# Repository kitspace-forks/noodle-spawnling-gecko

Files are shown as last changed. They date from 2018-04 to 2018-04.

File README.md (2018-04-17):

# Noodle Spawnling Gecko Brain

This is a brain for a [noodle spawnling](http://roboticarts.zoness.com/2017/12/19/birthing-a-noodle-spawnling/), a small 3d-printed robot figurine designed by spetku.

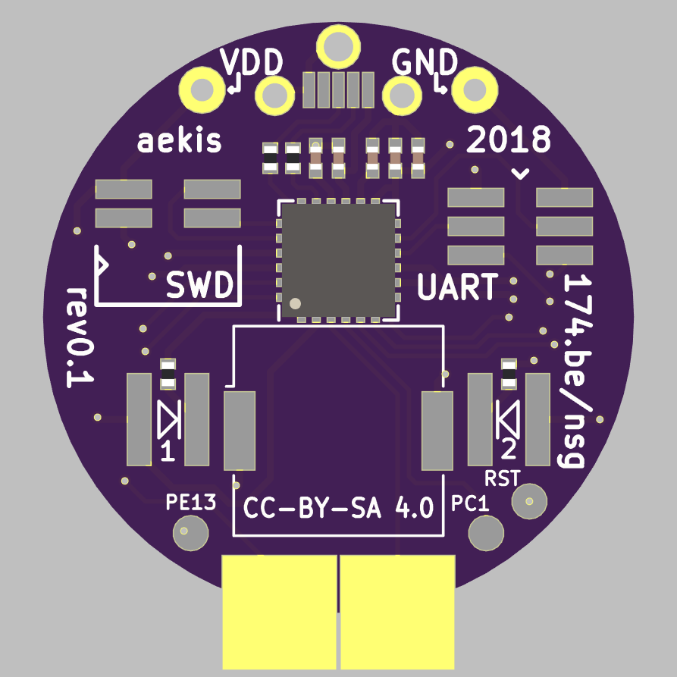
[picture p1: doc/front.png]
Rendered view of the PCB front side


I am building a noodle spawnling for myself and also wanted to learn more about programming ARM Cortex uCs, so I made this brain board to do both at the same time.

## Features
  * Silicon Labs Happy Gecko EFM32HG309 microcontroller (the same one as on the [tomu.im](https://tomu.im))
  * buzzer
  * 2 LEDs
  * capacitive touch button area
  * micro USB connector
  * SWD debug and a combined (LEU/US)ART header
  * CR2032 coincell holder

For the BOM see [doc/bom.csv](doc/bom.csv).

## Additional tools
Besides KiCad, some additional tools were used on this project:
  * For BOM management I used [BOMs Away](https://github.com/Jeff-Ciesielski/Boms-Away)
  * [doc/stickerbom.pdf](doc/stickerbom.pdf) was generated with [StickerBOM](https://github.com/adamgreig/agg-kicad/wiki/StickerBOM)

## License
CC BY-SA 4.0 (https://creativecommons.org/licenses/by-sa/4.0/)

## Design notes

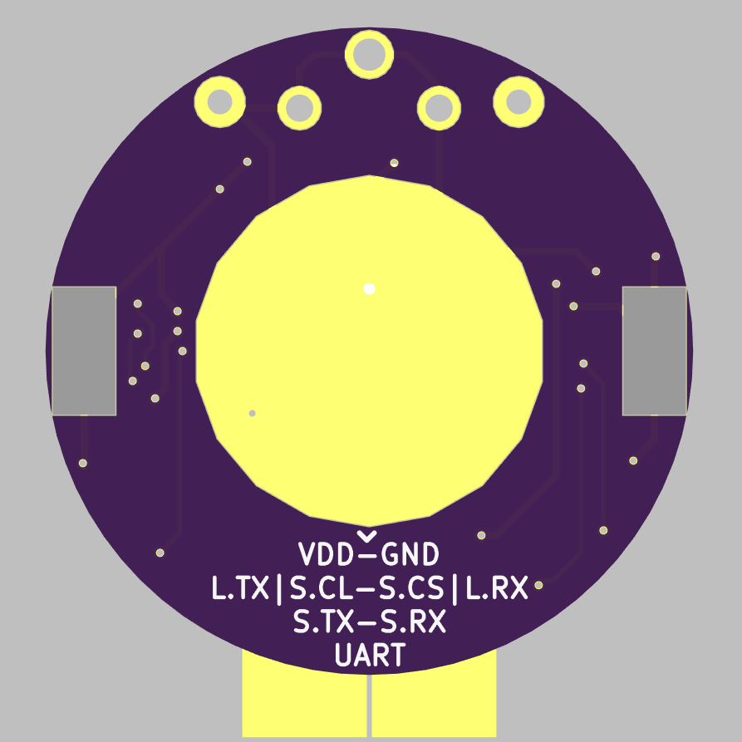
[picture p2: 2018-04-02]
doc/back.png

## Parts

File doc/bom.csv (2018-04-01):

Refs | Value | Footprint | QTY | MFR | MPN | SPR | SPN
BZ1 | Buzzer | Buzzers_Beepers:Buzzer_Murata_PKMCS0909E4000-R1 | 1 | Murata Electronics North America | PKMCS0909E4000-R1 | Digikey | 490-9647-1-ND
C5 | 100nF | Capacitors_SMD:C_0402_NoSilk | 1 | Samsung Electro-Mechanics | CL05A104KQ5NNNC | Digikey | 1276-1442-1-ND
C4 | 10uF | Capacitors_SMD:C_0402_NoSilk | 1 | Murata Electronics North America | GRM155C80J106ME11D | Digikey | 490-13233-1-ND
C3;C2 | 1uF | Capacitors_SMD:C_0402_NoSilk | 2 | Samsung Electro-Mechanics | CL05X105KQ5NNNC | Digikey | 1276-1754-1-ND
C1 | 4.7uF | Capacitors_SMD:C_0402_NoSilk | 1 | Samsung Electro-Mechanics | CL05A475KQ5NRNC | Digikey | 1276-1481-1-ND
U1 | EFM32HG309 | Housings_DFN_QFN:QFN-24-1EP_5x5mm_Pitch0.65mm | 1 | Silicon Labs | EFM32HG309F64G-B-QFN24 | Digikey | 336-3896-ND
R3;R4 | 15 Ohm | Resistors_SMD:R_0402_NoSilk | 2 | Panasonic Electronic Components | ERJ-2RKF15R0X | Digikey | P15.0LCT-ND
R1;R2 | R | Resistors_SMD:R_0402_NoSilk | 2 | Yageo | RC0402FR-0752R3L | Digikey | YAG3180CT-ND
BT1 | Battery_Cell | coincell_smd:CR2032_holder_smd | 1 | Linx Technologies Inc. | BAT-HLD-001 | Digikey | BAT-HLD-001-ND
J5 | EXT_PWR_GND | headers-tht:Pin_d1.0mm_L10.0mm_noSilk | 1 | Amphenol FCI | 68000-401HLF | Digikey | 609-3466-ND
J4 | EXT_PWR_VDD | headers-tht:Pin_d1.0mm_L10.0mm_noSilk | 1 | Amphenol FCI | 68000-401HLF | Digikey | 609-3466-ND
J7 | DEBUG_HEADER | headers_smd:header_smd_0.05pitch_2row_4pin | 1 | Sullins Connector Solutions | GRPB022VWQS-RC | Digikey | S9012E-02-ND
J6 | LEU0/US0_HEADER | headers_smd:header_smd_0.05pitch_2row_6pin | 1 | Amphenol FCI | 20021121-00006C4LF | Digikey | 609-3693-1-ND
SW1 | CAP_TOUCH_BTN | pcb_pads:cap_touch_pads | 1 | - | - | - | -
D1;D2 | LED | pcb_pads:led_5mm_horizontal_pads | 2 | Wurth Electronics Inc. | 151051SS04000 | Digikey | 732-11405-ND
J1 | GPIO_PC1_PAD | pcb_pads:pcb_pad_single_1,5mm | 1 | - | - | - | -
J2 | GPIO_PE13_PAD | pcb_pads:pcb_pad_single_1,5mm | 1 | - | - | - | -
J3 | RESETn_PAD | pcb_pads:pcb_pad_single_1,5mm | 1 | - | - | - | -
J8 | USB_MICRO_B | usb_smd:usb_microb_smd_vertical | 1 | Molex, LLC | 1051330011 | Digikey | WM10134CT-ND

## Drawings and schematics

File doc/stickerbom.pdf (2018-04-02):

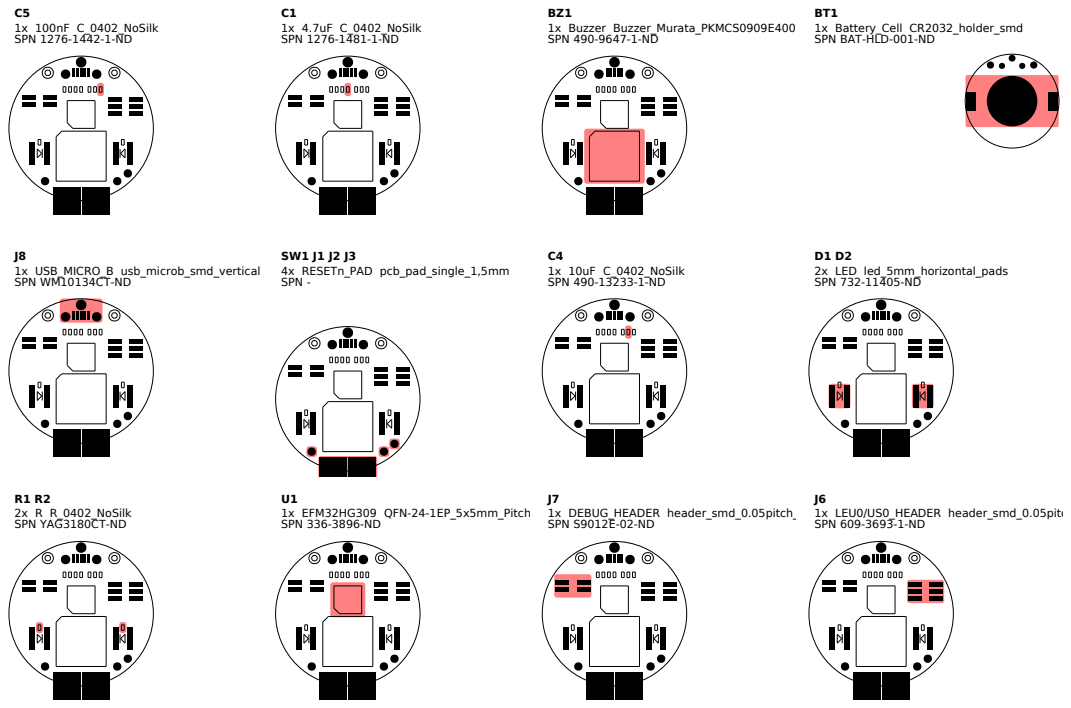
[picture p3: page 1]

J4 J5
2x EXT_PWR_GND Pin_d1.0mm_L10.0mm_noSilk SPN 609-3466-ND

R3 R4
2x 15 Ohm R_0402_NoSilk
SPN P15.0LCT-ND

C3 C2
2x 1uF C_0402_NoSilk
SPN 1276-1754-1-ND

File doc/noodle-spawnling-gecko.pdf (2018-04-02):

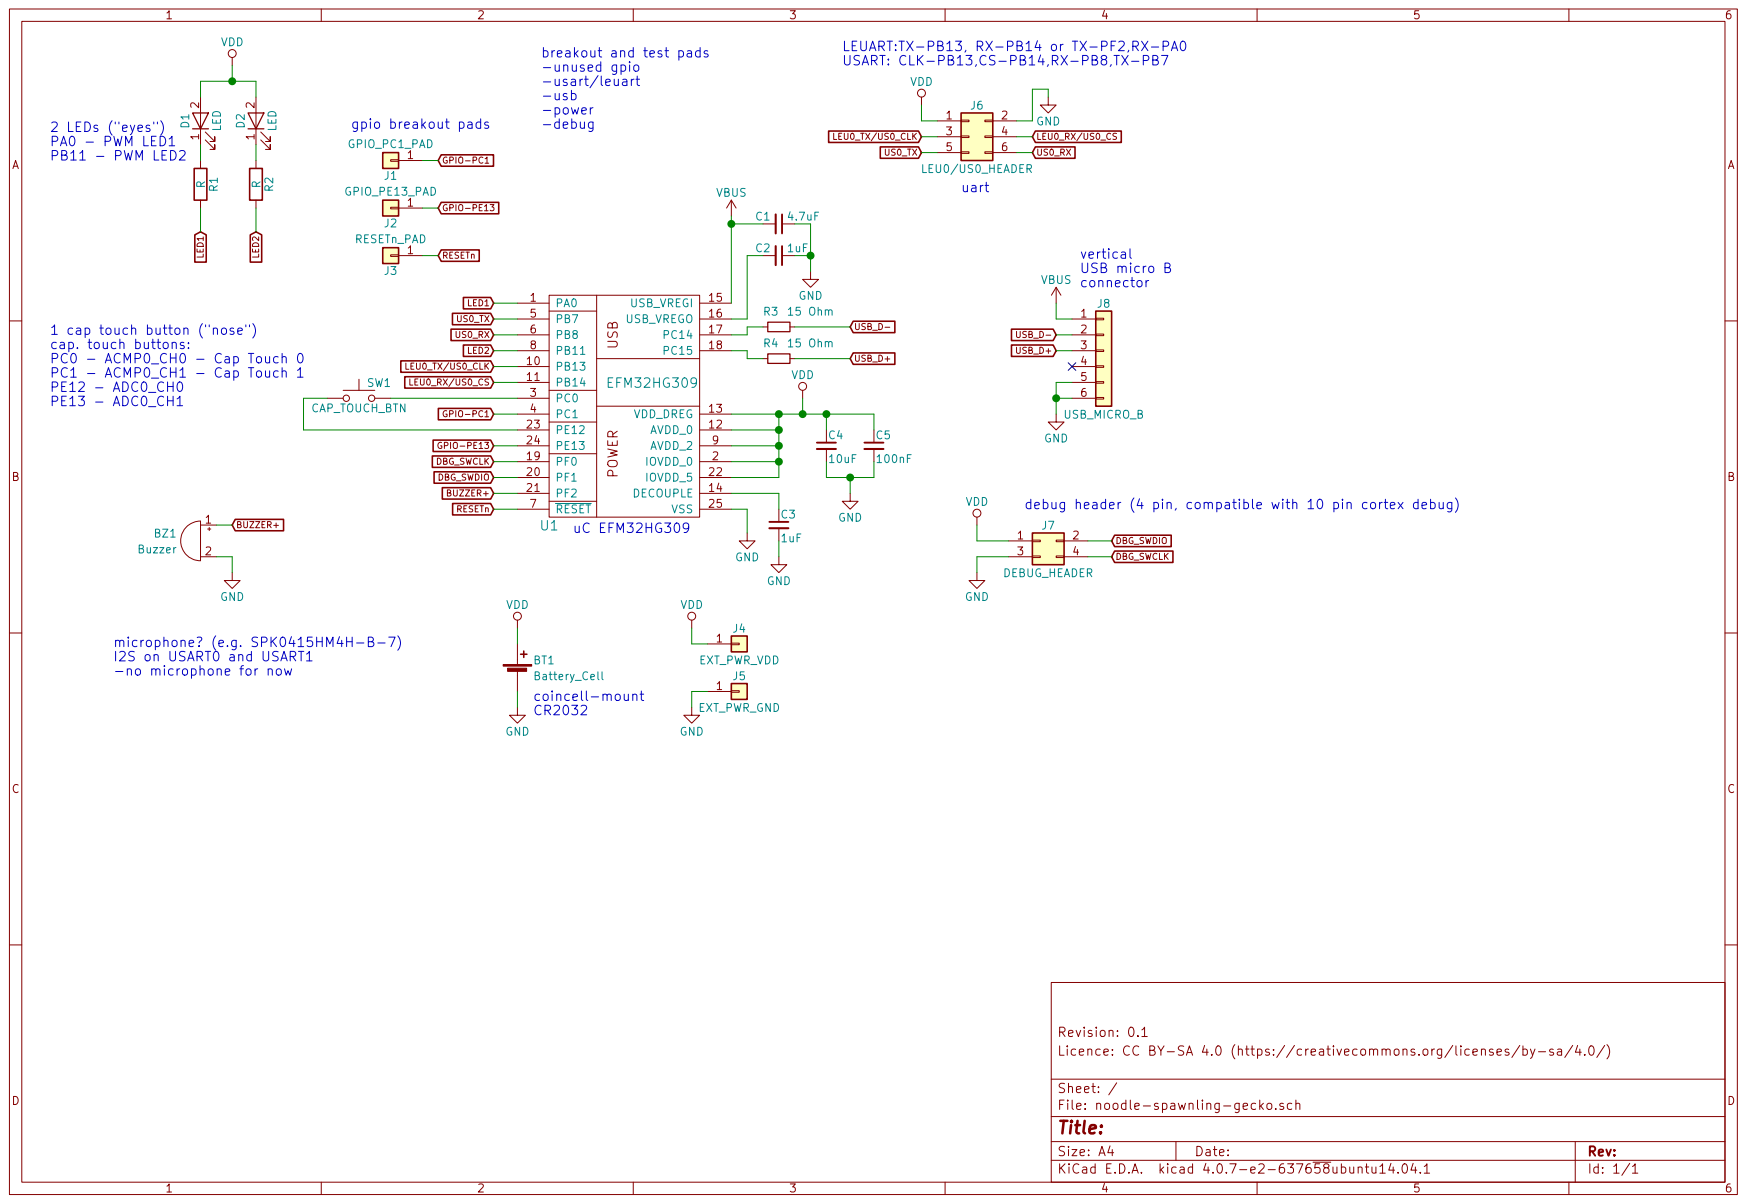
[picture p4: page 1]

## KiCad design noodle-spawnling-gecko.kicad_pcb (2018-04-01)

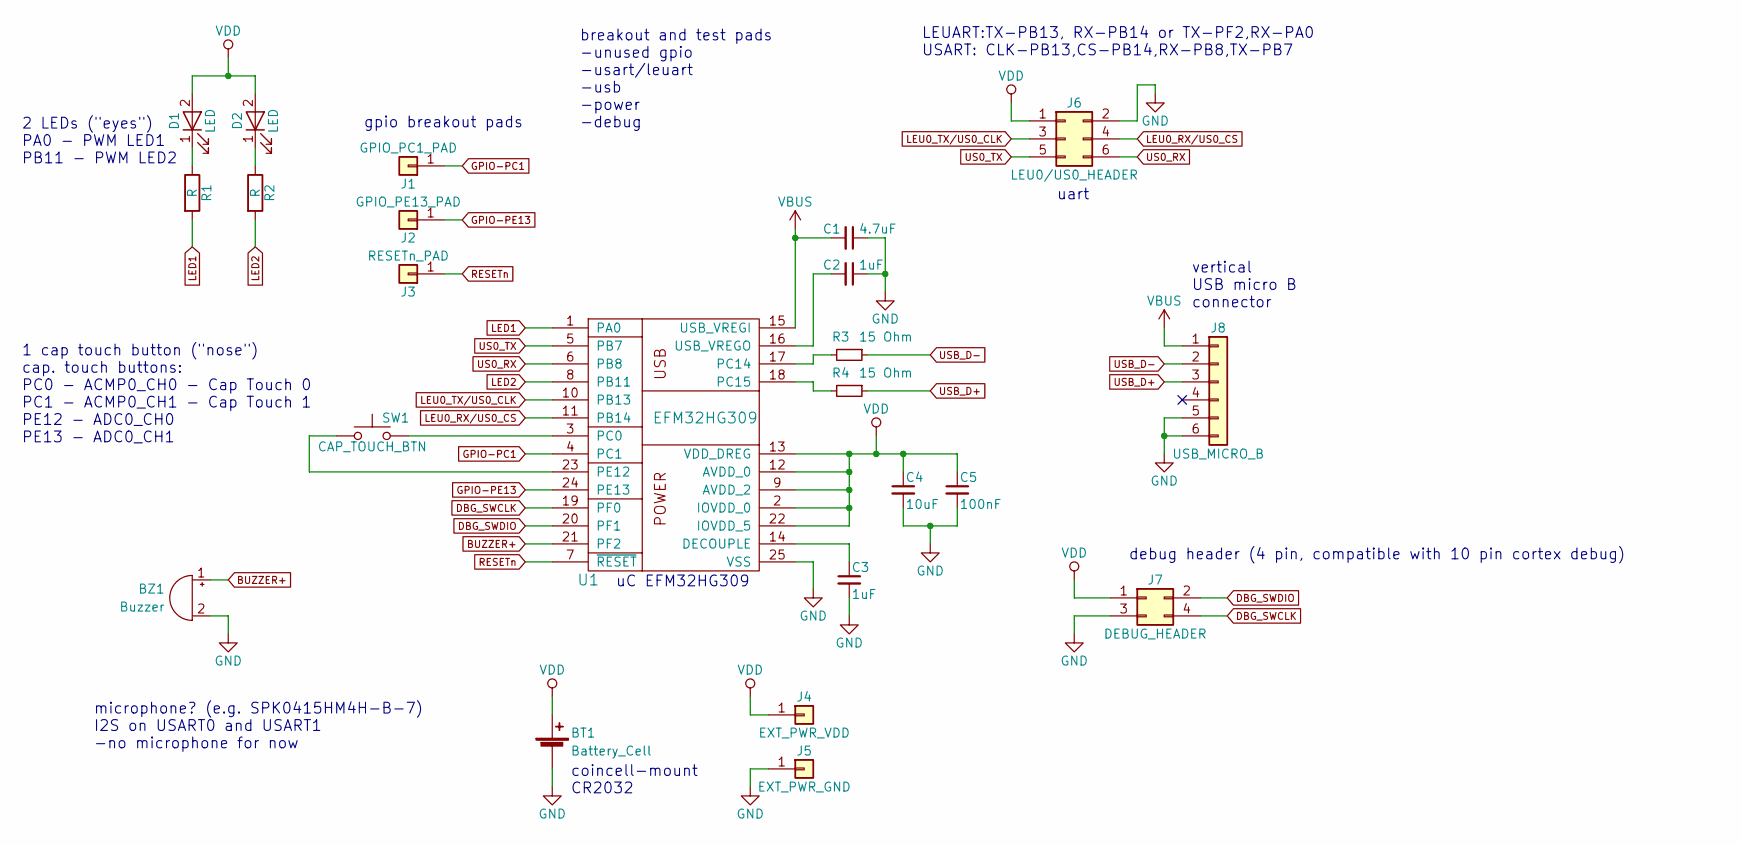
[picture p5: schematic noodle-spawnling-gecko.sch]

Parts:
BT1: Battery_Cell; CR2032_holder_smd
BZ1: Buzzer; Buzzer_Murata_PKMCS0909E4000-R1
C1: 4.7uF; C_0402_NoSilk
C2, C3: 1uF; C_0402_NoSilk
C4: 10uF; C_0402_NoSilk
C5: 100nF; C_0402_NoSilk
D1, D2: LED; led_5mm_horizontal_pads
J1: GPIO_PC1_PAD; pcb_pad_single_1,5mm
J2: GPIO_PE13_PAD; pcb_pad_single_1,5mm
J3: RESETn_PAD; pcb_pad_single_1,5mm
J4: EXT_PWR_VDD; Pin_d1.0mm_L10.0mm_noSilk
J5: EXT_PWR_GND; Pin_d1.0mm_L10.0mm_noSilk
J6: LEU0/US0_HEADER; header_smd_0.05pitch_2row_6pin
J7: DEBUG_HEADER; header_smd_0.05pitch_2row_4pin
J8: USB_MICRO_B; usb_microb_smd_vertical
R1, R2: R; R_0402_NoSilk
R3, R4: 15 Ohm; R_0402_NoSilk
SW1: CAP_TOUCH_BTN; cap_touch_pads
U1: EFM32HG309; QFN-24-1EP_5x5mm_Pitch0.65mm

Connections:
BUZZER+: BZ1.1 (-), U1.21 (PF2)
DBG_SWCLK: J7.4, U1.19 (PF0)
DBG_SWDIO: J7.2, U1.20 (PF1)
GND: BT1.2 (-), BZ1.2 (+), C1.1, C2.1, C3.2, C4.2, C5.2, J5.1, J6.2, J7.3, J8.5, J8.6, U1.25 (VSS)
GPIO-PC1: J1.1, U1.4 (PC1)
GPIO-PE13: J2.1, U1.24 (PE13)
LED1: R1.2, U1.1 (PA0)
LED2: R2.2, U1.8 (PB11)
LEU0_RX/US0_CS: J6.4, U1.11 (PB14)
LEU0_TX/US0_CLK: J6.3, U1.10 (PB13)
unnamed: C2.2, U1.16 (USB_VREGO)
unnamed: C3.1, U1.14 (DECOUPLE)
unnamed: D1.1 (K), R1.1
unnamed: D2.1 (K), R2.1
unnamed: R3.2, U1.17 (PC14)
unnamed: R4.2, U1.18 (PC15)
unnamed: SW1.1, U1.23 (PE12)
unnamed: SW1.2, U1.3 (PC0)
RESETn: J3.1, U1.7 (~RESET)
US0_RX: J6.6, U1.6 (PB8)
US0_TX: J6.5, U1.5 (PB7)
USB_D+: J8.3, R4.1
USB_D-: J8.2, R3.1
VBUS: C1.2, J8.1, U1.15 (USB_VREGI)
VDD: BT1.1 (+), C4.1, C5.1, D1.2 (A), D2.2 (A), J4.1, J6.1, J7.1, U1.2 (IOVDD_0), U1.9 (AVDD_2), U1.12 (AVDD_0), U1.13 (VDD_DREG), U1.22 (IOVDD_5)

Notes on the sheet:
uC EFM32HG309
2 LEDs ("eyes") PA0 - PWM LED1 PB11 - PWM LED2
debug header (4 pin, compatible with 10 pin cortex debug)
coincell-mount CR2032
vertical USB micro B connector
breakout and test pads -unused gpio -usart/leuart -usb -power -debug
microphone? (e.g. SPK0415HM4H-B-7) I2S on USART0 and USART1 -no microphone for now
LEUART:TX-PB13, RX-PB14 or TX-PF2,RX-PA0 USART: CLK-PB13,CS-PB14,RX-PB8,TX-PB7
1 cap touch button ("nose") cap. touch buttons: PC0 - ACMP0_CH0 - Cap Touch 0 PC1 - ACMP0_CH1 - Cap Touch 1 PE12 - ADC0_CH0 PE13 - ADC0_CH1
gpio breakout pads
uart

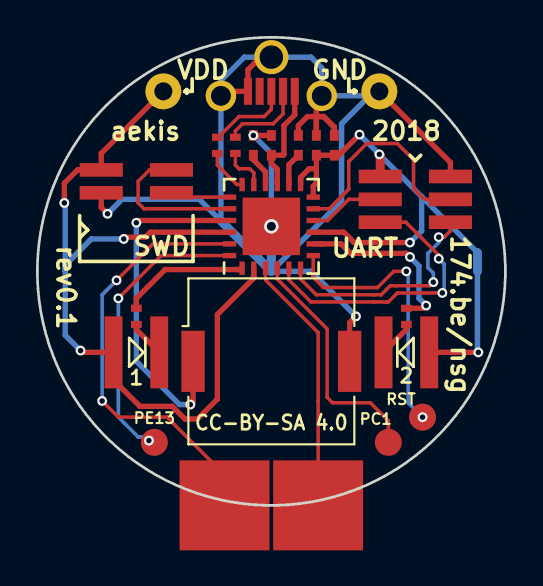
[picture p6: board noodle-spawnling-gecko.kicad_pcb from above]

Board: 2 copper layers, 26.0 x 26.0 mm, 23 parts (1 on the bottom side), 25 nets.

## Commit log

2018-04-01 initial commit; revision 0.1
    [noodle-spawnling-gecko.kicad_pcb, noodle-spawnling-gecko.sch]
2018-04-01 add license to the silkscreen
    [noodle-spawnling-gecko.kicad_pcb]
2018-04-01 add bom
    [bom.csv, noodle-spawnling-gecko.sch]
2018-04-02 add schematic pdf and board render photos

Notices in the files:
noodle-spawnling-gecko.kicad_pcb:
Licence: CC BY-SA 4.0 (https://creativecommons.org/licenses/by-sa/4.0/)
